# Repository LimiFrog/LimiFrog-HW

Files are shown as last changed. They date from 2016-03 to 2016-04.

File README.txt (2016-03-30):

LimiFrog-HW, ReadMe file
========================

This repository contains hardware information related to the LimiFrog harwdare: board, module assemble, casing...

******
NOTE: 
Datasheets of Integrated Circuits used on the board and other information of direct interest for programmers is stored in repository LimiFrog-SW, under directory "documentation"
*******

Contents of LimiFrog-HW repo :
-----------------------------

/3D-PRINTABLE_CASES :
Sources files (openscad) and STL files to 3D-print protective cases for LimiFrog.

/MODULE_HW :
Instructions to assemble and manipulate safely LimiFrog.

/BOARD :
Board design information

.
Example software for this board can be found in repo LimiFrog-SW. The /documentation directory present there also contains some hardware information that is of direct interest to programmers.

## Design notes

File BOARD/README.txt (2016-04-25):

Directory Contents :
-------------------

> LimiFrog_Board_Main_Parts_And_Interconnections.pdf
  --> Overview of the main parts present on the board and their interconnections

> LimiFrog_0.2a_SchematicDoc.pdf
  --> Full board schematic, provided under the Attribution-NonCommercial-ShareAlike 4.0 International license (CC BY-NC-SA). 
      See ../Licenses.txt .

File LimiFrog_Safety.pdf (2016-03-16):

### SAFETY RECOMMENDATIONS for LimiFrog users

V0.1 – March 2016

1) Never involve LimiFrog in any way in a medical or life-sustaining device.
2) LimiFrog is a prototyping platform and should not be used “as is” an an end-product.
3) LimiFrog includes a LiPo (lithium-polymer) battery.

A set of safety recommendations provided by the manufacturer of the battery is available in the product specification, which can be found on-line at this location : https://github.com/LimiFrog/LimiFrog-HW/blob/master/MODULE_HW/Battery_Specification.pdf

For convenience a copy of the safety paragraph is provided below :

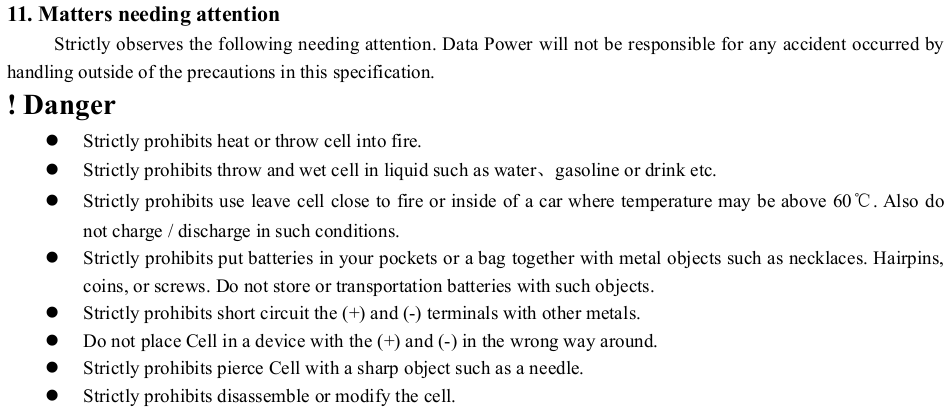
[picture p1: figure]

(continued on next page)

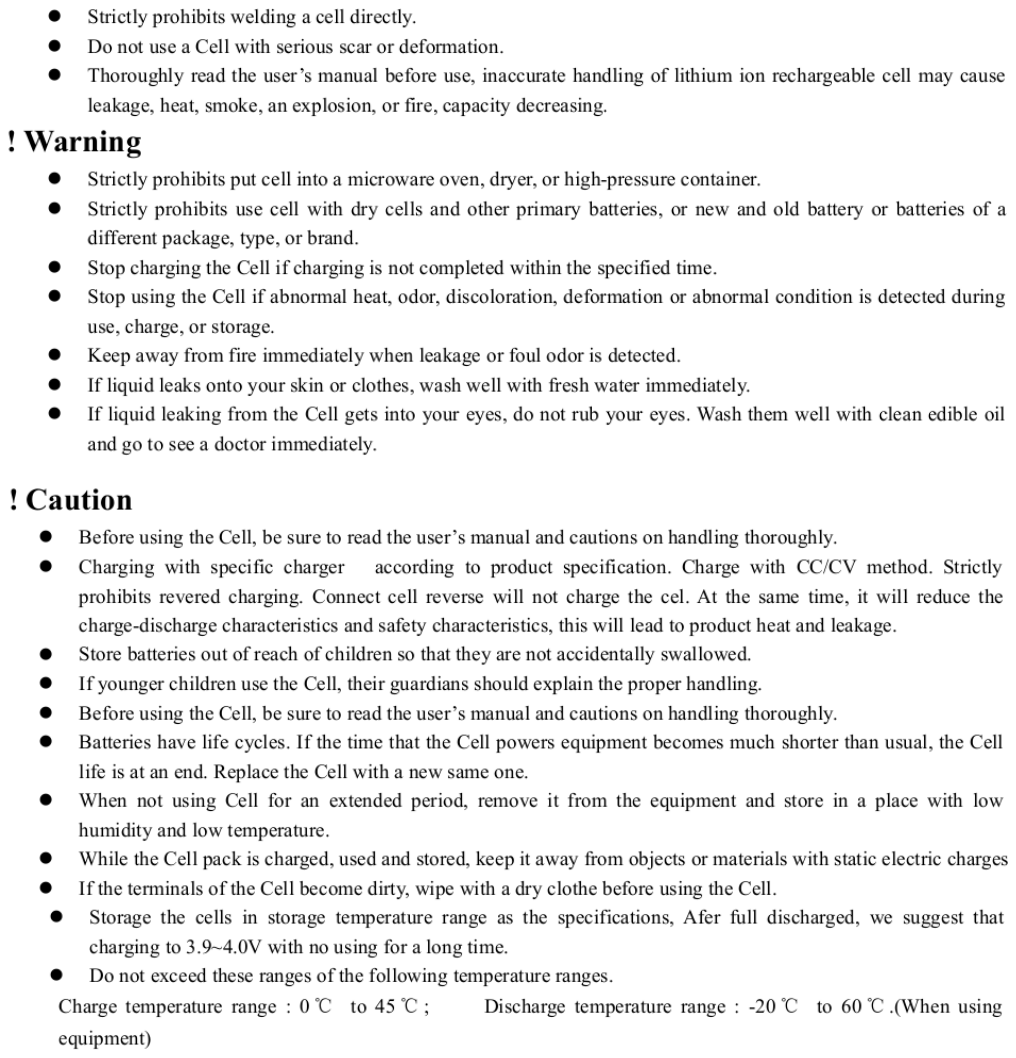
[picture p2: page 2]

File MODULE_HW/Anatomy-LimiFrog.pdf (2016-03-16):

OLED Display

# Anatomy of LimiFrog

Case opening for

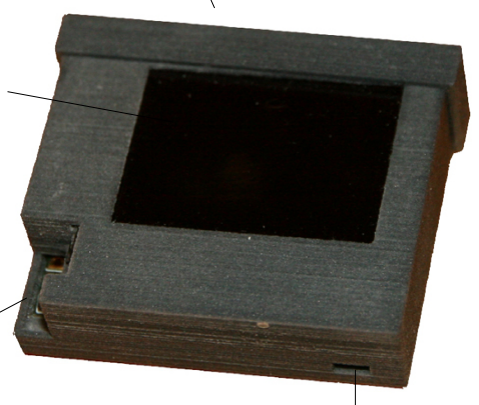
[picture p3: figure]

ambient light sensor /
proximity detector
Slot for sound to
microphone

Removable lid

BACK

STM32 Program /
Debug interface
(SWD)

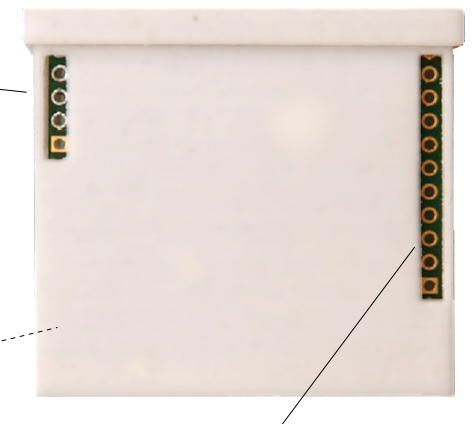
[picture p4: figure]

Extension port
(configurable digital/analog interfaces)

TOP (Lid Removed)

Micro-USB plug
(receptacle)

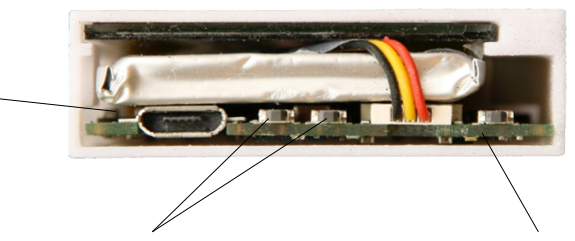
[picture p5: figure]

ON/OFF switch
(mini push-button)
+ See next page

LimiFrog-0.1 :
2 general-purpose switches (mini push-button)
LimiFrog-0.2:
1 general-purpose switch

(Not exposed here)
BlueTooth module
SWD interface
(optional use)

Operation of ON/OFF switch (mini push-button)

> From OFF state:
Press ON/OFF switch for about 0.5s to switch ON

> From ON state:

- ON/OFF signal routed to STM32 GPIO, behavior software-dependent. The provided software implements a “soft power off”:
Briefly pressing ON/OFF triggers an interrupt that switches off the full board after 3 brief LED flashes.
- Press ON/OFF switch for >5 s to cause a “hard power off” :
Board is switched off without CPU intervention.
(Useful in case STM32 code has hung and cannot execute the soft power off sequence)

External ON/OFF

> The ON/OFF signal driven by the push-button is also routed to the outermost position of the 5-pin connector that bears the STM32 SWD interface. This allows to control the ON/OFF signal from outside the board (e.g. by connecting to an external switch) rather than from the small push-button. The external switch must pull ON/OFF low to assert it and leave it open when not asserting it.

# LimiFrog-0.2 Board – Top and Bottom Views

## TOP VIEW

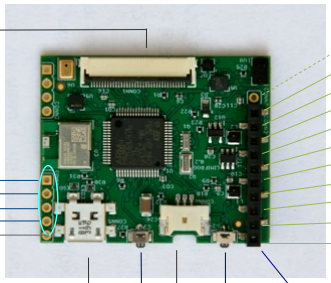
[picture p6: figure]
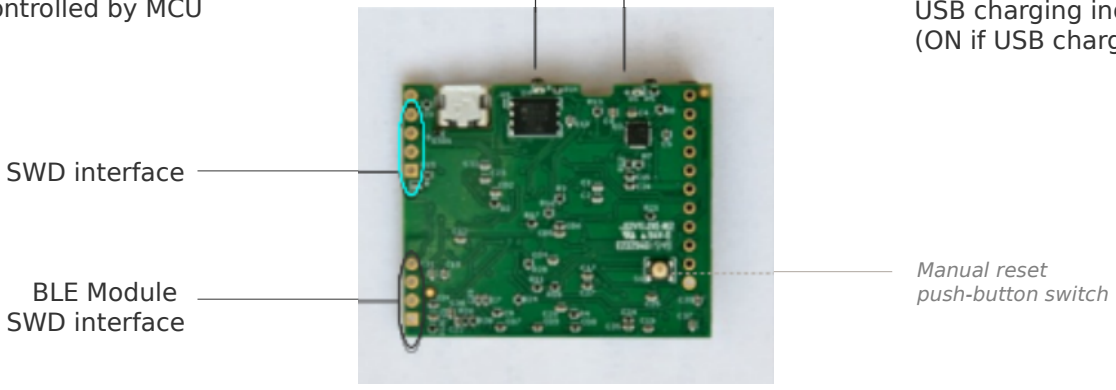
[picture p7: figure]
BLE Module; push-button switch; SWD interface

## BOTTOM VIEW

LED D4
RED
Controlled by MCU

LED D1
AMBER
USB charging indicator
(ON if USB charging)

STM32
SWD
interface

#1: VCC

#2: GND

#3: SWCK

#4: SWDIO

Extension Port
Position 1: Analog MIC output (also PB10) Position 2: digital GPIO (PA6)
Position 3: digital GPIO (PA4)
Position 4: digital GPIO (PA3)
Position 5: digital GPIO (PA2) Position 6: VCC_LDO (OFF or 3.3V) Position 7: digital GPIO (PA1) Position 8: digital GPIO (PA0) Position 9: GND
Position 10: digital GPIO (PB8) Position 11: digital GPIO (PB9) #5: external ON/OFF

STM32 SWD interface

ON/OFF

General Purpose
Push-Button Switch

Manual reset

Battery Connector

USB Connector

OLED Display
Connector

Female Socket Connector
on ext port positions 2 to 11 (dual top+bottom entry)

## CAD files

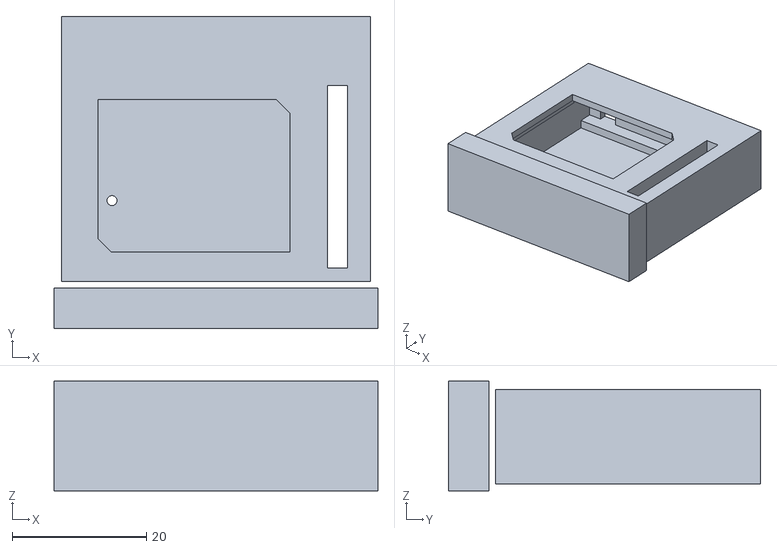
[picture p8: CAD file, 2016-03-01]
3D-PRINTABLE_CASES/Model_C-1.5.stl
48.2 x 46.5 x 16.4

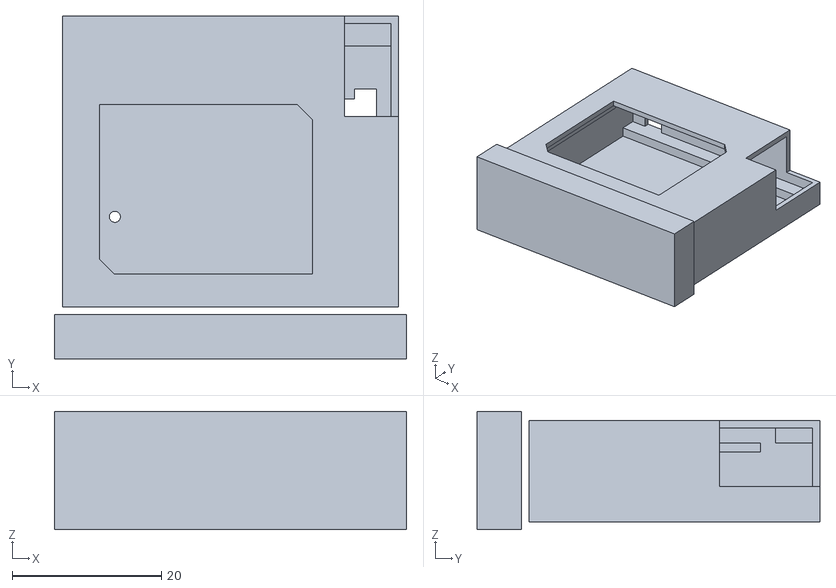
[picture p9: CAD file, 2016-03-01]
3D-PRINTABLE_CASES/Model_D-1.stl
47.2 x 46.0 x 15.8

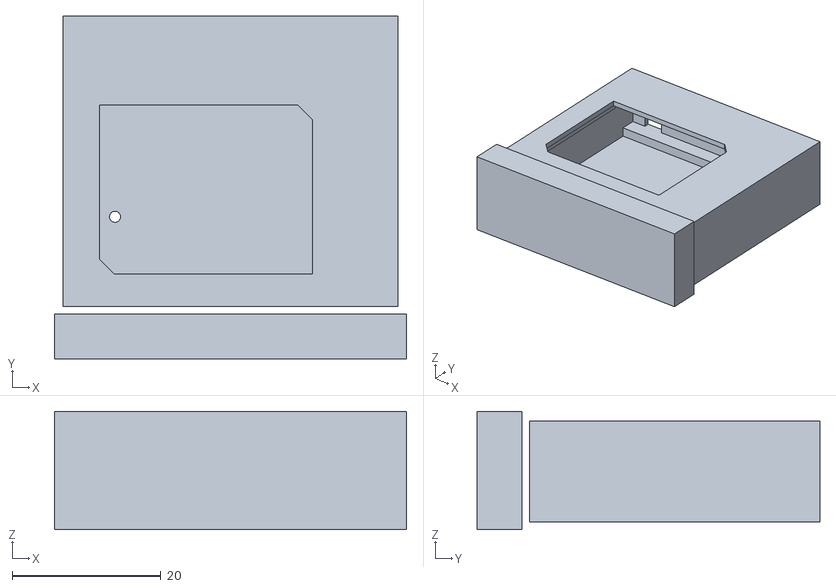
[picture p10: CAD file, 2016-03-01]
3D-PRINTABLE_CASES/Model_E-1.stl
47.2 x 46.0 x 15.8

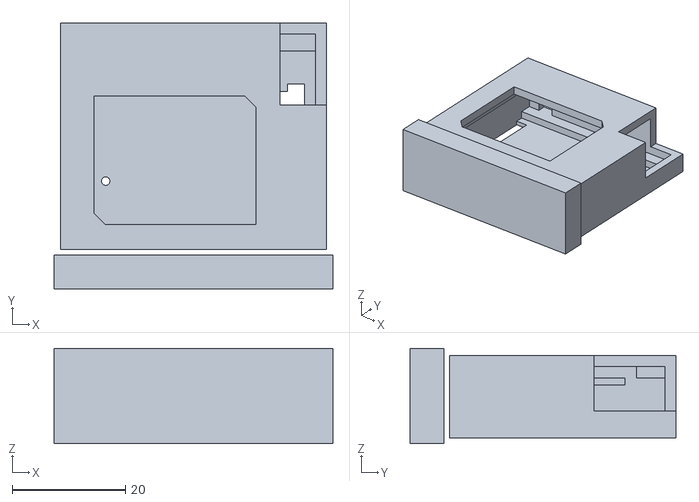
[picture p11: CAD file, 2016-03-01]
3D-PRINTABLE_CASES/Model_A-2.stl
49.2 x 47.0 x 16.9

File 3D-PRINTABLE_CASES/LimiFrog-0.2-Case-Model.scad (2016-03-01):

/**************************************************/
/*  This is a model of case for LimiFrog 0.2      */
/*  (the version shipped to Kickstarter backers)  */
/*                                                */
/* It is intended for a stacked configuration,    */
/* the battery lies between the board and the     */
/* display                                        */
/* The user may choose to enable/disable the      */
/* generation of some geometries (typically,      */
/* openings for connectors) by commenting out some*/
/* sections of this code.                         */
/* Wall thickness can also be configured.         */
/**************************************************/

/**************************************************/
/* The XY plane is parallel to the display,       */
/* Z axis is normal to the display.               */
/*                                                */
/* Code does the following:                       */
/* - describe 7 stacked "slices" along XY plane   */
/*   Each slice is described in 2D then extruded  */
/*    along Z axis                                */
/* - then add openings for the VL6180X sensor,    */
/*   for the microphone, for the extension port,  */
/*   for the program & debug connectros etc.      */
/* - finally lid is described                     */
/**************************************************/


/* == Construction Parameters  ===================*/ 

// You may want to change the following
Twall = 1;      // Wall thickness
Twall_lid = 1;  // Lid wall thickness 


// Better not change this unless you know what 
// you're doing

epsilon = 0.5;

Xboard=42.4; // real size 42.4 , will add some margin when computing Xin
Yboard=35;   // real size 34.6 + some margin

Yflex = 3;   // to accomodate curve of flexible connector from board to display

// Internal dimensions of the case :
Xin = Xboard + 0.6;  
Yin = Yboard + Yflex;

// Screen (i.e. display) dimensions + slight margin
// (real dimensions @ no margin = 35.8x30.8)
Xscreen = 36; 
Yscreen=31; 

// (X-)Margin that allows display to slide within the guide
ScreenMargin = 0.8;

// Distance between holes for extension port
// and holes for STM32/BME SWD ports
LR_Connectors_Dist = 15*2.54;


// Slice 1 parameters
h1 = 1; // = thickness of box bottom

// Slice 2 parameters
h2 = 1+0.8; // = thickness of PCB + bottom-side components

// Slice 3 parameters
h3 = 2; // = max thickness of top components

// Slice 4 parameters
h4 = 4.6; // = max battery thickness
// Side battery blockers suppressed

// Slice 5 parameters
h5 = 1.2; // = thickness of OLED supports (rails) - also allows to squeeze battery wires

// Dimesion of the rails over which the OLED display
// is expected to slide
X_OledSupport = 1.3;
Y_OledSupport_left = Yscreen;
Y_OledSupport_right = Yscreen*0.7;

// Slice 6 parameters
h6 = 1.7+0.3; // = thickness of OLED + slight margin
Ybutee = 5; Xbutee = 1; //dimensions of stop part that prevents OLED to slide too far inside the case
 
// Slice 7 parameters
h7 = Twall; // = thickness of box top
// dimensions of active region of the display:
Xdisplay_active = 28.6; 
Ydisplay_active = 22.7; 
// Translation factors to get the case opening to match the position of the display's active region
Display_LeftMargin = 3.9; 
Display_TopMargin = 5.9; 

// Parameters for openings for VL6180X and mic
Y_VL6180X_CornerOpen= 9.5+Yflex; 
Mic_opening_Xleft = 2.9;
Mic_opening_Xright =6.9;
Mic_opening_Z = 2;



/* == Now actually describe the case =============*/ 

// Generic module re-used multiple times below
module shell_TopView()
{
    difference()
    {
        translate([-Twall,0,0])
        square([Xin+2*Twall, Yin+Twall]);
        
        square([Xin, Yin]);
    }
}


// ----------------------------------------------
// Slice 1 (bottom of box)
module slice1_TopView()
{
        translate([-Twall,0,0])
        square([Xin+2*Twall, Yin+Twall]);
}
    
module slice1()
{
    linear_extrude(height=h1)slice1_TopView();
}
    

// ----------------------------------------------
// Slice 2 -- PCB + bottom components padding
module slice2_TopView()
{
    difference()
    {
        translate([-Twall,0,0])
        square([Xin+2*Twall, Yin+Twall]);
        
        square([Xin, Yboard]);
    }
}
module slice2()
{
    linear_extrude(height=h2)
        slice2_TopView();
}
    

// ----------------------------------------------
// Slice 3 -- Top components + some margin
module slice3_TopView()
{
    shell_TopView();
}
module slice3()
{
    linear_extrude(height=h3)
        slice3_TopView();
}
    

// ----------------------------------------------
// Slice 4 -- Battery side 
module slice4_TopView()
{
    shell_TopView();
 // no side blockers anymore
}
module slice4()
{
    linear_extrude(height=h4)
        slice4_TopView();
}
    

// ----------------------------------------------
// Slice 5 -- OLED support (rails)
module slice5_TopView()
{
    shell_TopView();
    square([X_OledSupport, Y_OledSupport_left]); 
    translate([Xscreen-X_OledSupport,0,0])
      square([Xin-Xscreen+X_OledSupport, Y_OledSupport_right]);
}
module slice5()
{
    linear_extrude(height=h5)
        slice5_TopView();
}
    
// ----------------------------------------------
// Slice 6 -- OLED guide (rails)
module slice6_TopView()
{
    difference()
    {
        translate([-Twall,0,0])
        square([Xin+2*Twall, Yin+Twall]);
        
        square([Xscreen+ScreenMargin, Yin]);
     /* ONLY IF NO TOP OPENING ON EXT PORT :   
        //Also,  remove material for cost optimisation :
        translate([Xscreen+ScreenMargin, 3, 0])
            square([Xin-(Xscreen+ScreenMargin),3]);
        translate([Xscreen+ScreenMargin, 9, 0])
            square([Xin-(Xscreen+ScreenMargin),3]);
        translate([Xscreen+ScreenMargin, 15, 0])
            square([Xin-(Xscreen+ScreenMargin),3]);
     */
    }
    
  translate([0, Yin-Ybutee, 0])
    square([Xbutee, Ybutee]);
    
}
module slice6()
{
    linear_extrude(height=h6)
        slice6_TopView();
}
    

// ----------------------------------------------
// Slice 7 -- box top with opening
module slice7_TopView()
{
    difference()
    {
        translate([-Twall,0,0])
        square([Xin+2*Twall, Yin+Twall]);
        
        translate([Display_LeftMargin, 
        Yin-(Ybutee+Display_TopMargin+Ydisplay_active),0])
        square([Xdisplay_active, Ydisplay_active]);
    }
    
    // "Fill" 2 opposite corners for aesthetic & robustness
    Screen_TopRightX = Display_LeftMargin+Xdisplay_active;
    Screen_TopRightY = Yin-(Ybutee+Display_TopMargin);
    Screen_BotLeftX = Display_LeftMargin;
    Screen_BotLeftY = Yin-(Ybutee+Display_TopMargin+Ydisplay_active);

    polygon(points=[ [Screen_TopRightX,Screen_TopRightY],
                     [Screen_TopRightX-2,Screen_TopRightY],
                     [Screen_TopRightX,Screen_TopRightY-2] 
                    ]);
    polygon(points=[ [Screen_BotLeftX,Screen_BotLeftY],
                     [Screen_BotLeftX+2,Screen_BotLeftY],
                     [Screen_BotLeftX,Screen_BotLeftY+2] 
                    ]);

}
module slice7()
{
    linear_extrude(height=h7)
        slice7_TopView();
}
    

// ----------------------------------------------
// Assemble the above slices into complete case :

module box_tmp()
{
  union()
  {
    slice1();
    
    translate([0, 0, h1])
    slice2();

    translate([0, 0, h1+h2])
    slice3();
    
    translate([0, 0, h1+h2+h3])
    slice4();

    translate([0, 0, h1+h2+h3+h4])
    slice5();

    translate([0, 0, h1+h2+h3+h4+h5])
    slice6();

    translate([0, 0, h1+h2+h3+h4+h5+h6])
    slice7();
  }
}



/* == Add various openings to the case   ==========*/ 


module VL6180X_CornerCut()
{
    translate([Xscreen+ScreenMargin-0.01, Yin-Y_VL6180X_CornerOpen, h1+h2+h3]) 
      cube([Xin+Twall-(Xscreen+ScreenMargin)+epsilon, Y_VL6180X_CornerOpen+Twall+epsilon, h7+h6+h5+h4]);
}



module Mic_Opening()
{
  translate([Mic_opening_Xleft, Yin-epsilon, h1+h2])
     cube([Mic_opening_Xright-Mic_opening_Xleft, Twall+2*epsilon , Mic_opening_Z]);
}


module stm32SWD_Opening() //but posn5 (Boot0) not accessible
{
   X_hole = 3;
   Y_hole = 5*2.54 + 2.54/4;  // header pitch=2.54 mm
   translate([0,0,-2])
      cube([X_hole,Y_hole,5]);
    
   // Mark position 1
   translate([6, Y_hole-2.54/2, -2]) 
     linear_extrude(height=5)
      circle(d=1.5, $fn=16);
      
}

module bleSWD_Opening()
{
   X_hole = 3;
   Y_hole = 4*2.54+2.54/4;  // header pitch=2.54 mm
   translate([0,2+8*2.54,-2])
      cube([X_hole,Y_hole,5]);
}

module ExtensionPins_Opening() 
{
   X_hole = 3;
   Y_hole = 10*2.54 + 2.54 + 2.54/2;  // header pitch=2.54 mm
   translate([LR_Connectors_Dist, 0, -2]) 
     cube([X_hole,Y_hole,5]);
}

module ResetButton_Opening() 
{
   X_RstBut = 5;
   Y_RstBut = 5;  
   translate([LR_Connectors_Dist-X_RstBut, 9*2.54, -2])
     cube([X_RstBut,Y_RstBut,5]);
}
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

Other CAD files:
3D-PRINTABLE_CASES/Model_E-1.5.stl
3D-PRINTABLE_CASES/Model_D-1.5.stl
3D-PRINTABLE_CASES/Model_A-1.5.stl
3D-PRINTABLE_CASES/Model_F-1.5.stl
3D-PRINTABLE_CASES/Model_A-1.stl
3D-PRINTABLE_CASES/Model_B-1.stl
3D-PRINTABLE_CASES/Model_F-1.stl
3D-PRINTABLE_CASES/Model_A-3.stl
3D-PRINTABLE_CASES/Model_B-1.5.stl

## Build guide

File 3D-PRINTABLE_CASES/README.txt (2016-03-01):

This directory contains 3D-printable models of protective cases for LimiFrog.

The models were built using the Openscad modelling software (can be freely downloaded on the web).
File LimiFrog-0.2-Case-Model.scad is the OpenScad source file.

Files Model_xxx.stl are all derived from this master source file, using different settings for wall thickness and presence/absence of some features.
File Case_Models.pdf lists the available variants.

You may also create your own variants by tinkering with the Openscad source file.

The STL format is suitable for usage with any 3D-printer or to send to an on-line 3D printing service.
There are free STL viewers available on-line if you want to view the proposed cases.

The choice of wall thickness depends on the capabilities of the target 3D printer and on the required robustness and rigidity of the printed case.

It is possible to use a wall thickness of 1mm to print this case using e.g. Sculpteo's online 3D-printing services, in basic white plastic (it's nylon, actually). The result is slightly flexible and reasonably robust (but not fit to sustain severe stress).
I have also used 1mm to print in ABS on a professional machine from a local 3D-printing specialist.
For DIY 3D-printers, 1.5 or 2mm thickness may be more appropriate.

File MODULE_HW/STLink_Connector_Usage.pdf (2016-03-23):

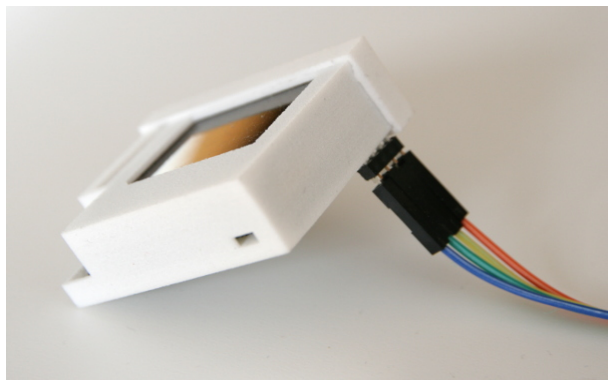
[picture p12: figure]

# Connecting your ST-Link device to LimiFrog

V0.2 – March 2016

## Reminder: Principle

ST-Link / V2
device

SWD interface (4 lines) :

- swclk (clock)
- swdio (data)
- vcc (positive supply)
- gnd (ground)

4

> An ST-Link/V2 device acts as a 'bridge' between a host PC and LimiFrog.
It enables downloading (and debuggging) code from the host PC into LimiFrog.

> It connects to the host PC via USB and
to LimiFrog via a specialized 'SWD' interface (4 wires).

> The SWD port provides access to the STM32 micro-controller.

ARM core
(STM32)

LimiFrog

Host PC

USB

## SWD port location on board

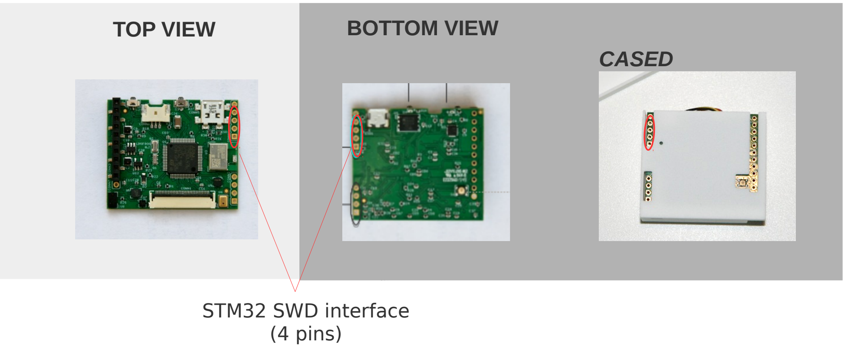
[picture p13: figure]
BOTTOM VIEW; STM32 SWD interface (4 pins); TOP VIEW; CASED

## Header and wires for connecting to LimiFrog's SWD port

> LimiFrog comes with a removable 4-pin male header that can be plugged into the SWD port of LimiFrog.

> One end of this 4-pin header is slightly 'swollen' : this end goes into the holes of the SWD port. The swelling facilitates mechanical contact, hence good electrical connection.
The other end plugs into the wires of e.g. four “Dupont Line” wires (provided).
“Dupont Line” type wires | 4-pin male header

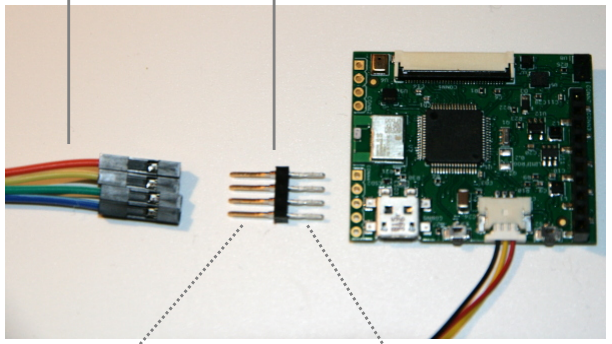
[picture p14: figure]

regular end | 'swollen' end

## Connecting to LimiFrog

Pin 4 = SWDIO (data)
Pin 3 = SWCLK (clock)
Pin 2 = GND | (ground reference)
Pin 1 = VCC | (positive supply, typ. 3V)

( Pin 5, not part of SDW interface )

Pin 1 indicator on plastic package

#4

#3

#2

#1

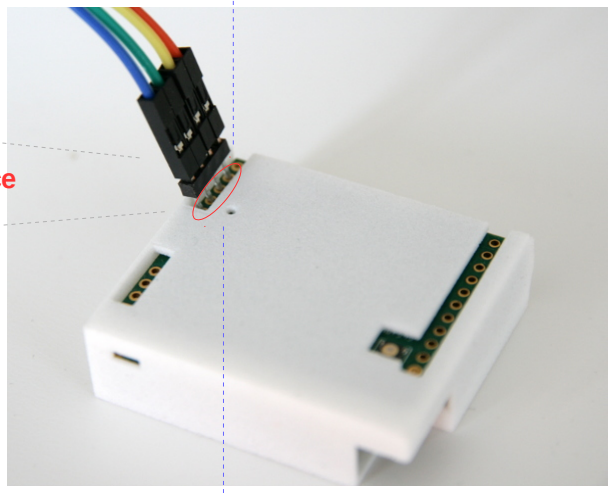
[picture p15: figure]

SWD interface

- Recommended installation when programming the board :
- The module weights on the 4-pin header

so electrical contact is facilitated.
- If proper contact is not established, press slightly downwards.

(#5)

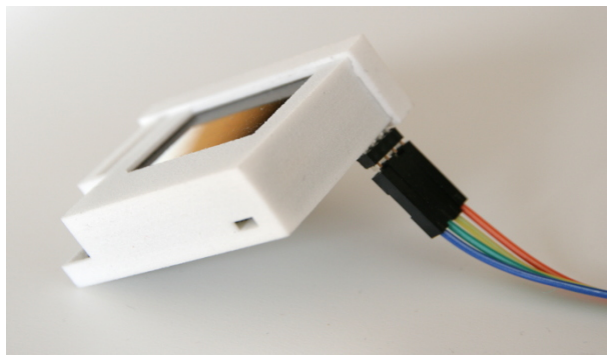
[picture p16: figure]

## Other side of the wires: ST-Link/V2 device (examples)

> Identify the following signals on your ST-Link/V2 device :
SWIDIO, SWCLK, GND, VCC/VDD
> Connect them to the relevant wires
> Next are a few examples : | Low-cost ST-Link/V2 compatible dongle
Nucleo Board used as ST-Link/V2 device (refer to STM32 Nucleo User Manual) | SWDIO

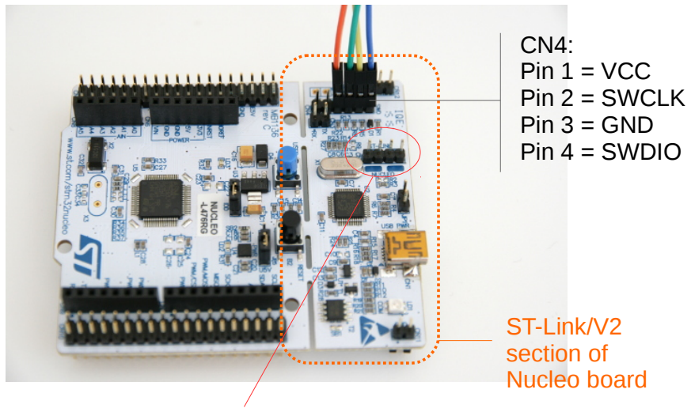
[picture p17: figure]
ST-Link/V2 section of Nucleo board; CN4: Pin 1 = VCC Pin 2 = SWCLK Pin 3 = GND Pin 4 = SWDIO
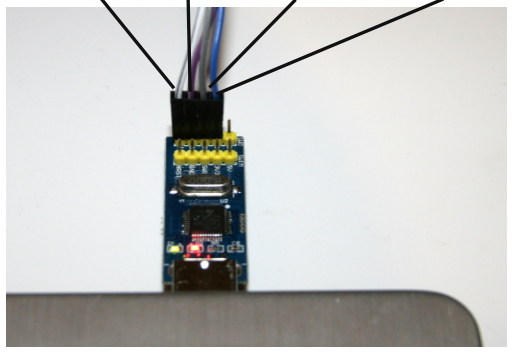
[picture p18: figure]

- Connector CONN2 must be removed to use Nucleo as stand-alone ST-Link/V2
- LimiFrog must be ON to provide 3V on Nucleo ST-Link/V2 VCC pin
SWCLK | GND | VCC

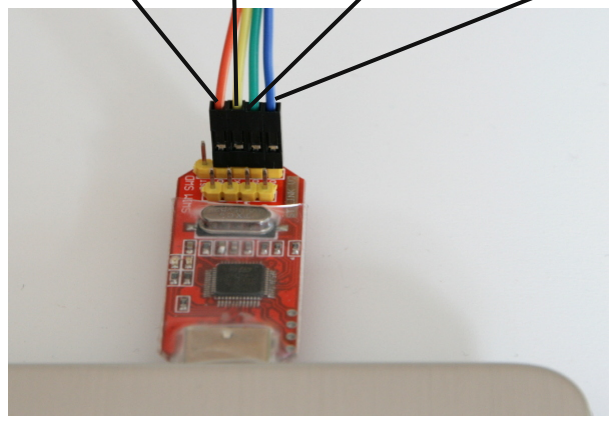
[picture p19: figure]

SWDIO | GND | SWCLK | VCC

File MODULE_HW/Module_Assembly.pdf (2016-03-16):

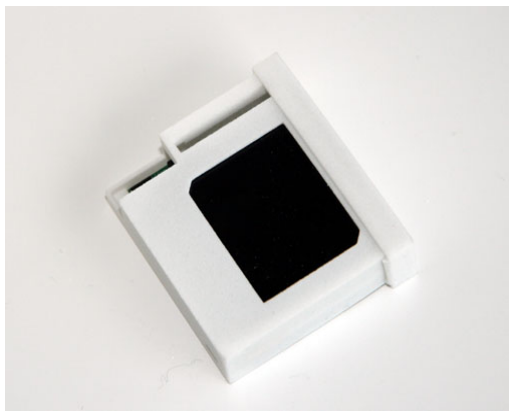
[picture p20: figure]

# Assembling your LimiFrog module

If your version of LimiFrog features no display and perhaps no case, just ignore the steps that pertain to these features.

V0.1 – March 2016

## Step 1: Beware of static electricity

First make sure you are not electrically charged.
To that aim, you could for example touch a metal part that is grounded to earth.

This is because, although reasonably well protected by specialized internal structures, integrated circuits can be damaged by electrostatic discharges (ESD)

## Step 2: Connect the LiPo battery

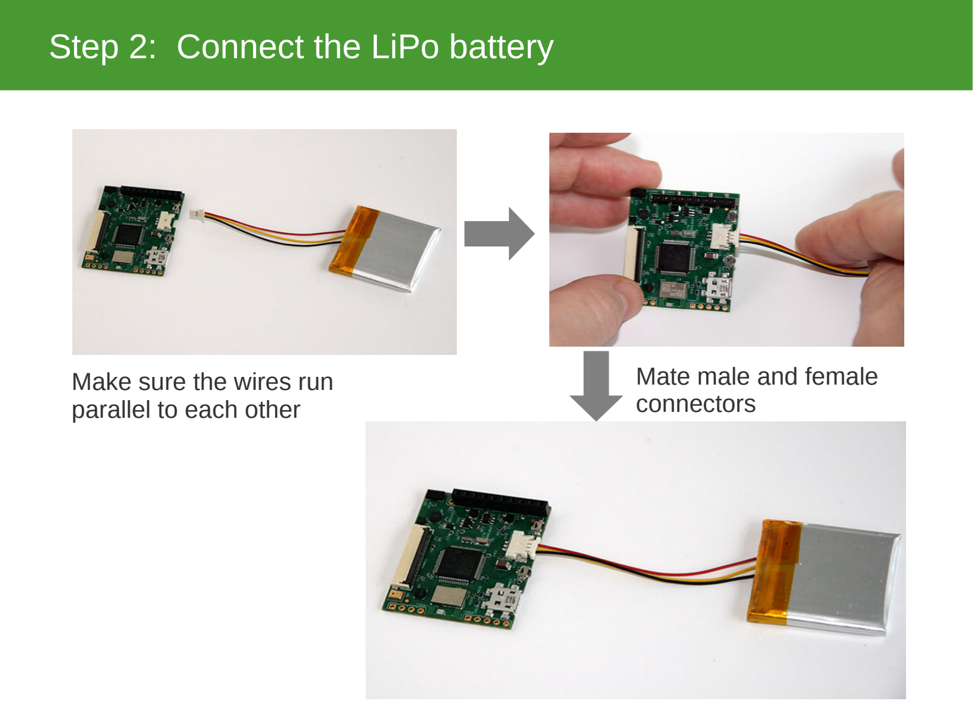
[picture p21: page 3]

Make sure the wires run
parallel to each other

Mate male and female
connectors

## Step 3: Connect the OLED display

a) Make sure the rotary backlock connector is open (pull up the black lever)
b) Fully insert the flexible OLED connector (a.k.a FPC) into the slot
of the backlock connector
*** Pay attention to OLED orientation (face down as on photo)

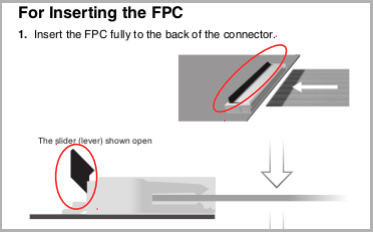
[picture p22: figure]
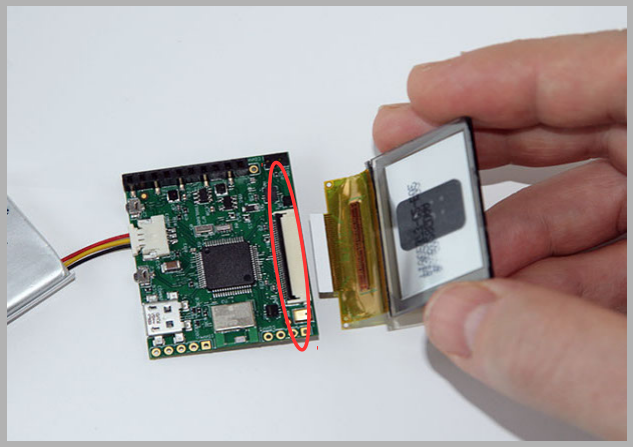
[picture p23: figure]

Manufacturer's recommendations for operating backlock connector copied at the end of this document and available in full on LimiFrog's GitHub, documentation, section: https://github.com/LimiFrog/LimiFrog-HW/Module_HW

=

## Step 3: Connect the OLED display (continued)

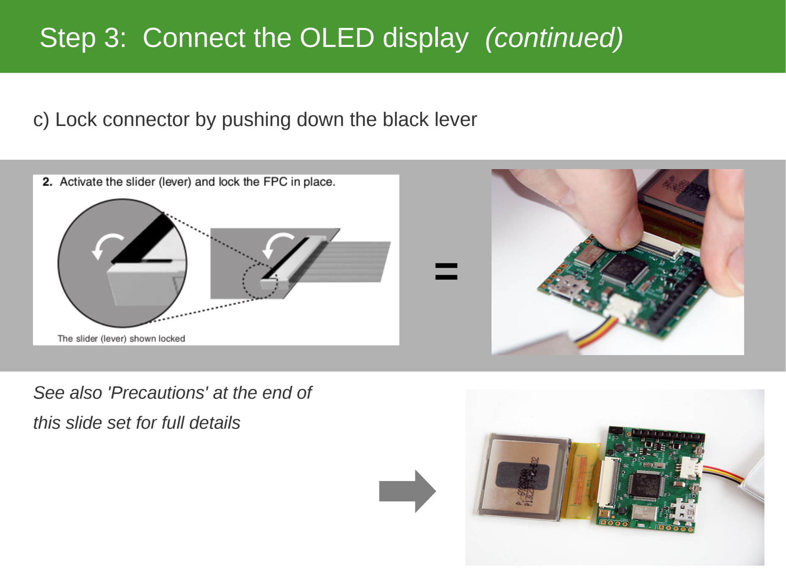
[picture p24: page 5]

c) Lock connector by pushing down the black lever

=

See also 'Precautions' at the end of this slide set for full details

## Step 4 : Stack the battery

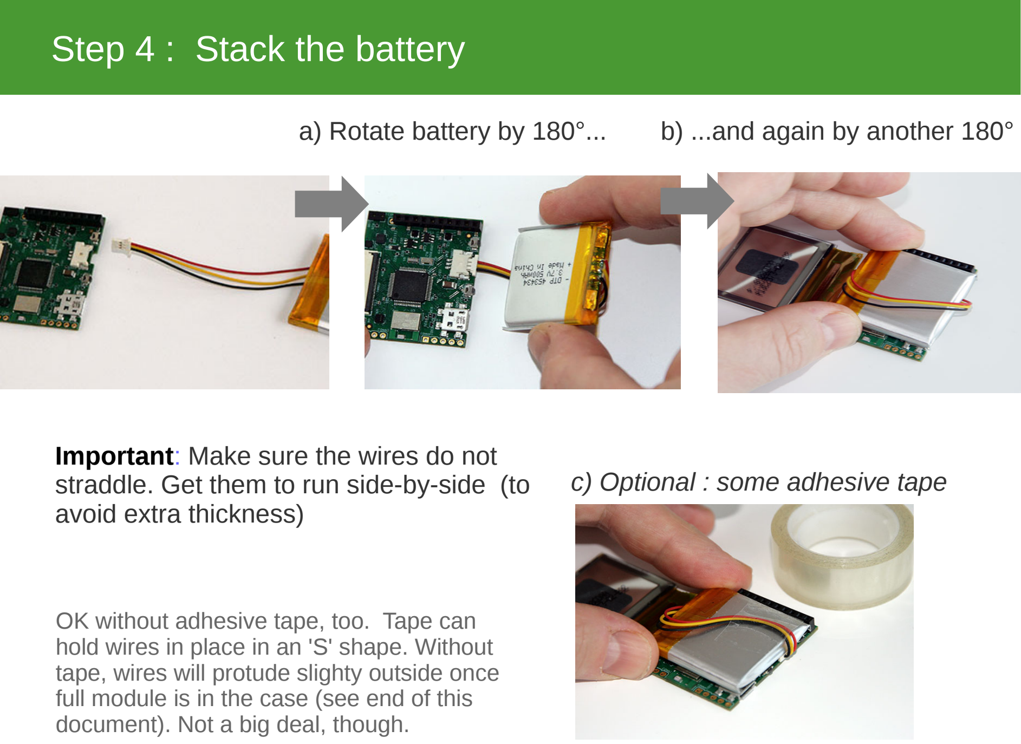
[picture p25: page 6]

a) Rotate battery by 180°... b) ...and again by another 180°
c) Optional : some adhesive tape

Important: Make sure the wires do not straddle. Get them to run side-by-side (to avoid extra thickness)

OK without adhesive tape, too. Tape can hold wires in place in an 'S' shape. Without tape, wires will protude slighty outside once full module is in the case (see end of this document). Not a big deal, though.

## Step 5 : Stack the OLED and insert module

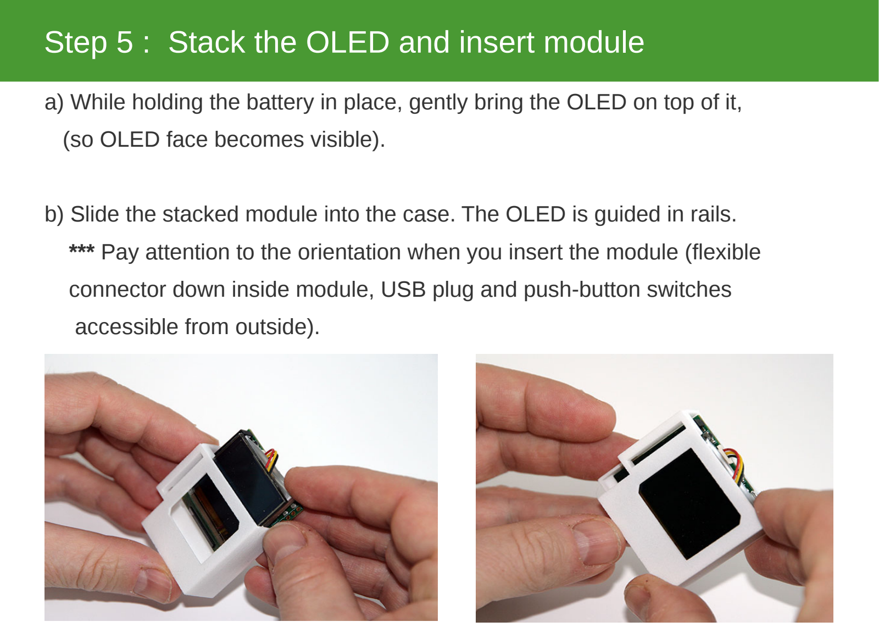
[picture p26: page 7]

a) While holding the battery in place, gently bring the OLED on top of it, (so OLED face becomes visible).
b) Slide the stacked module into the case. The OLED is guided in rails. *** Pay attention to the orientation when you insert the module (flexible connector down inside module, USB plug and push-button switches accessible from outside).

## Your LimiFrog module is ready for use !

Here battery wires were not maintained by
adhesive tape. They tend to protude a little outside the case (acceptable)

Here adhesive tape was used to hold the wires in a 'S' shape on top of battery and to prevent them from protuding a little.

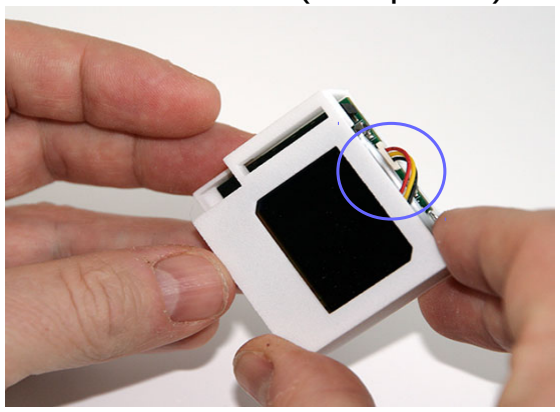
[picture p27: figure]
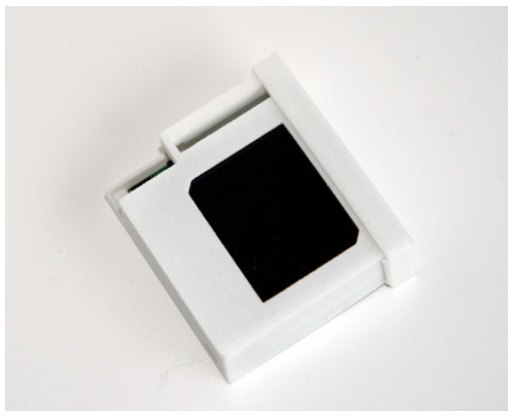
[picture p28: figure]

With the lid...

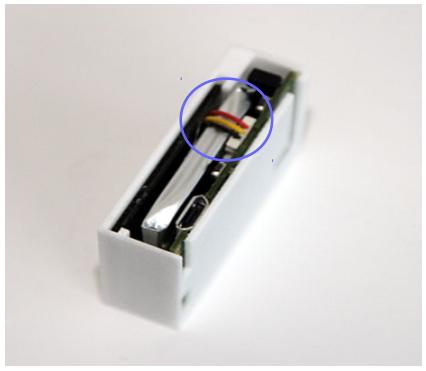
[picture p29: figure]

## APPENDIX (1) - In case you need to disconnect the display

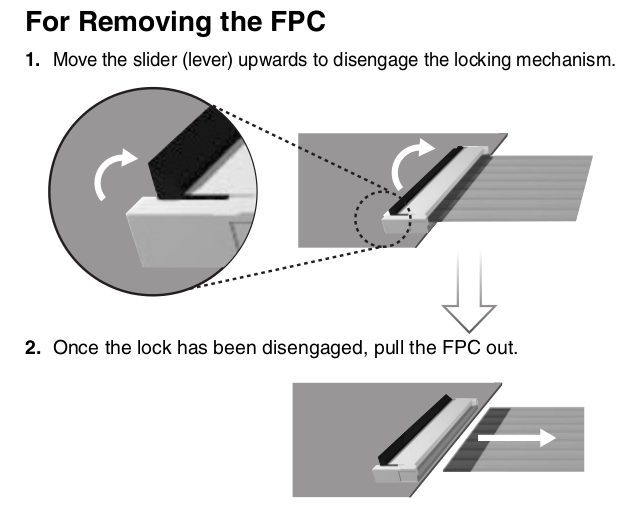
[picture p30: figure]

## Other precautions for FPC

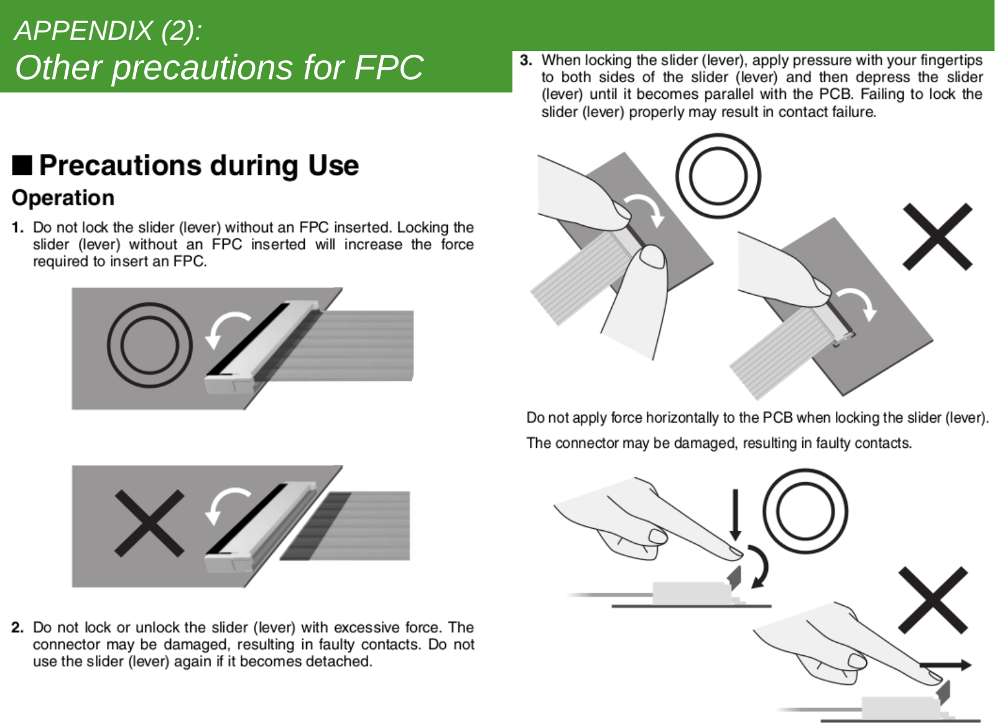
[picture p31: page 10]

APPENDIX (2):

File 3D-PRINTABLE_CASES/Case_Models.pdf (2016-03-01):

Sheet1

Page 1

Model Name | A-1 | B-1 | C-1 | D-1 | E-1 | F-1 | A-1.5 | B-1.5 | C-1.5 | D-1.5 | E-1.5 | F-1.5 | A-2
1mm | 1mm | 1mm | 1mm | 1mm | 1mm | 1.5mm 1.5mm 1.5mm | 1.5mm | 1.5mm | 1.5mm | 2mm
| Y | Y | Y | Y | Y | N | Y | Y | Y | Y | Y | N | Y
Hw reset button access | Y | Y | Y | Y | Y | N | Y | Y | Y | Y | Y | N | Y
| Y | Y | Y | N | N | N | Y | Y | Y | N | N | N | Y
| Y | Y | N | Y | N | N | Y | Y | N | Y | N | N | Y
| Y | N | N | N | N | N | Y | N | N | N | N | N | Y

Wall thickness

Bottom opening
For access to extension port

Top opening
For access to extension port

Opening for VL6180X
proximity sensor visibility

Opening for access to BLE
SWD interface

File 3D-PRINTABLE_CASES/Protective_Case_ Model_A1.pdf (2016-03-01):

- 1mm wall thickness, White plastic (nylon)
- Maximum access to connectors and ports :

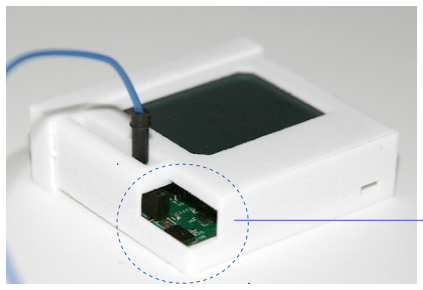
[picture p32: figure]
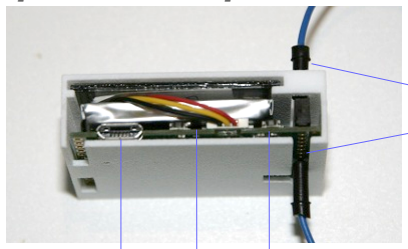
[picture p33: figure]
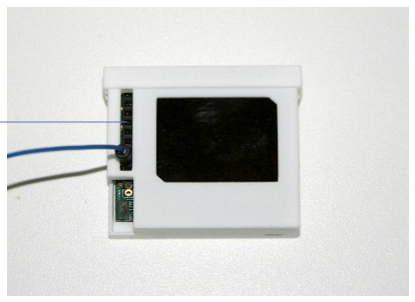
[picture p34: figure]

Top-side access to extension port positions 2 to 10

Case opening
for VL6180X optical detector visibility

Top (partial) and bottom (full) access to extension port (dual-entry female socket, 2.54m pitch)

USB connector

On/off mini-switch
General-purpose mini-switch

[with lid removed]

# 3D-printed case Model “A-1”

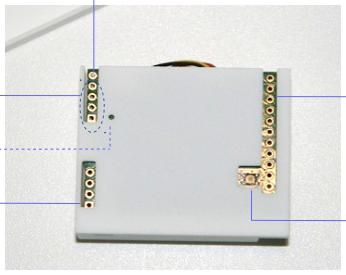
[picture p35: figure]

Bottom-side access
to extension port,
all positons (1 to 11)

Hardware reset
micro- push-button

Pins 1-4:
Access to STM32
SWD interface

Access to BLE module
SWD interface

STM32 SWD pin1 indicator

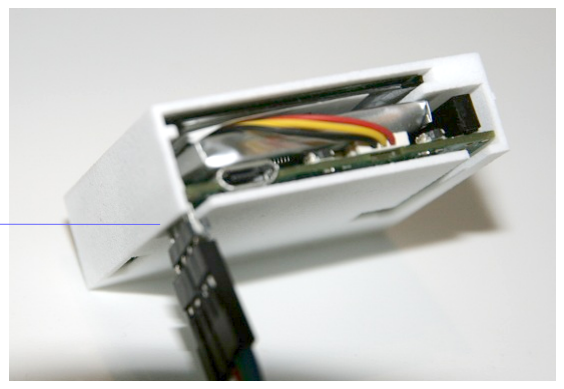
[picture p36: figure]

Pin5: ON/OFF access
(for optional external switch)

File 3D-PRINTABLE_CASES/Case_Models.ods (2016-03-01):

Model Name | A-1 | B-1 | C-1 | D-1 | E-1 | F-1 | A-1.5 | B-1.5 | C-1.5 | D-1.5 | E-1.5 | F-1.5 | A-2
Wall thickness | 1mm | 1mm | 1mm | 1mm | 1mm | 1mm | 1.5mm | 1.5mm | 1.5mm | 1.5mm | 1.5mm | 1.5mm | 2mm
Bottom opening For access to extension port | Y | Y | Y | Y | Y | N | Y | Y | Y | Y | Y | N | Y
Hw reset button access | Y | Y | Y | Y | Y | N | Y | Y | Y | Y | Y | N | Y
Top opening For access to extension port | Y | Y | Y | N | N | N | Y | Y | Y | N | N | N | Y
Opening for VL6180X proximity sensor visibility | Y | Y | N | Y | N | N | Y | Y | N | Y | N | N | Y
Opening for access to BLE SWD interface | Y | N | N | N | N | N | Y | N | N | N | N | N | Y

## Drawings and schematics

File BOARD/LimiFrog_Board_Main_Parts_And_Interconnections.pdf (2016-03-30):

# Hardware

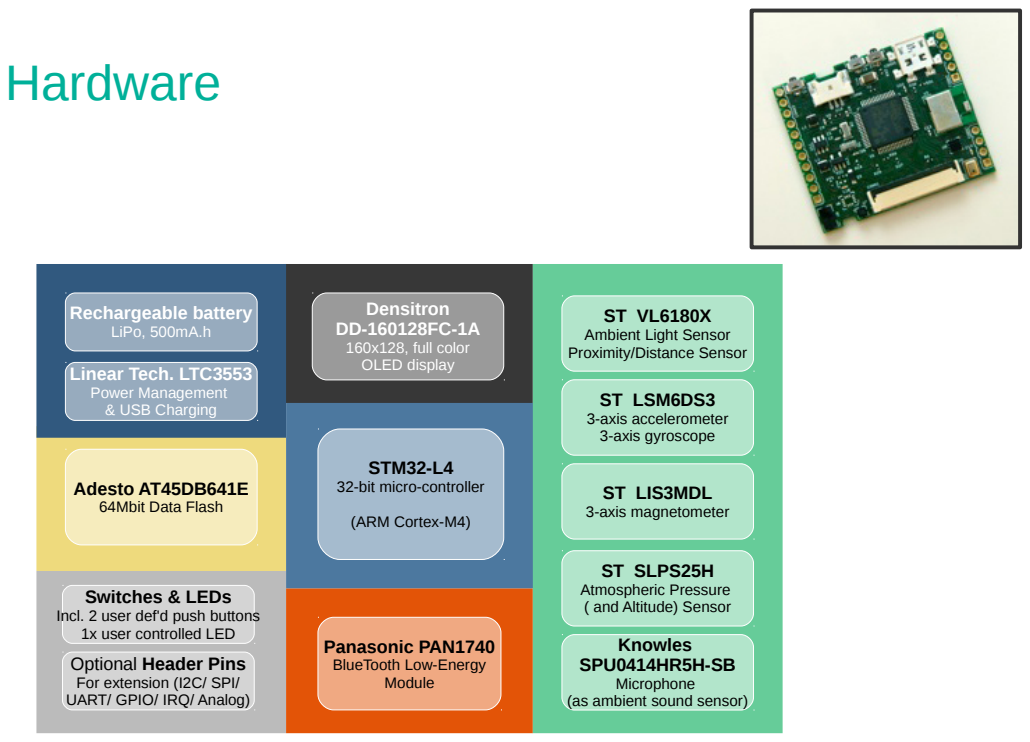
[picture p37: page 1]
(ARM Cortex-M4); Densitron DD-160128FC-1A 160x128, full color OLED display; Rechargeable battery LiPo, 500mA.h; Linear Tech. LTC3553 Power Management & USB Charging; Adesto AT45DB641E 64Mbit Data Flash; ST LSM6DS3 3-axis accelerometer 3-axis gyroscope; ST LIS3MDL 3-axis magnetometer

Ambient Light Sensor
Proximity/Distance Sensor

STM32-L4
32-bit micro-controller

ST SLPS25H
Atmospheric Pressure
( and Altitude) Sensor
Knowles
SPU0414HR5H-SB
Microphone
(as ambient sound sensor)

Switches & LEDs
Incl. 2 user def'd push buttons
1x user controlled LED
Optional Header Pins
For extension (I2C/ SPI/
UART/ GPIO/ IRQ/ Analog)

Panasonic PAN1740
BlueTooth Low-Energy
Module

# Major Connections

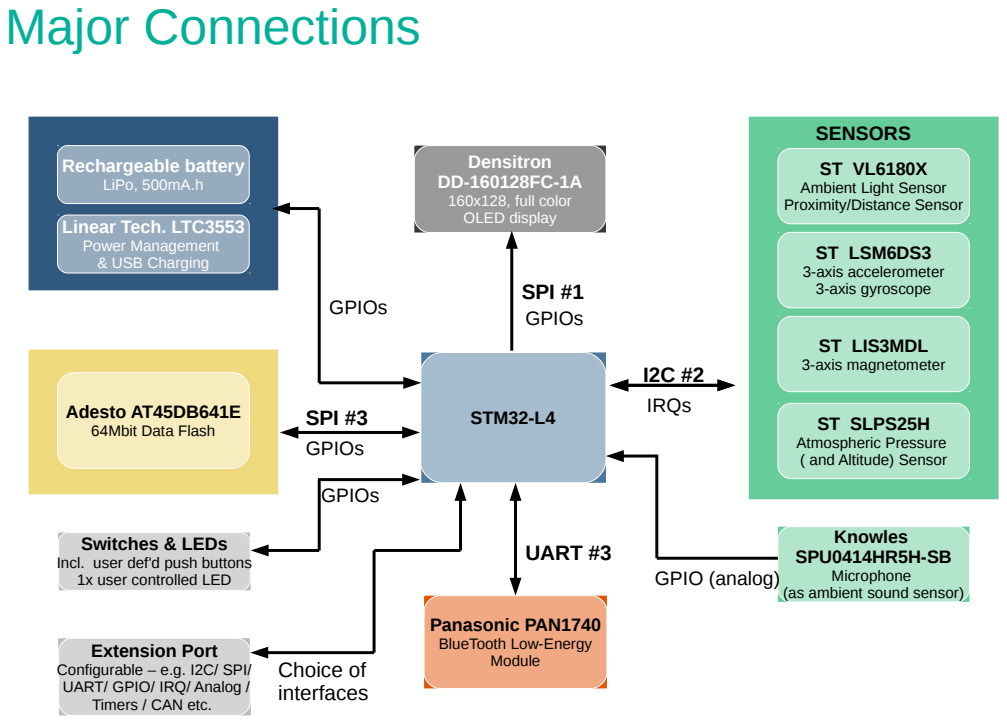
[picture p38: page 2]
STM32-L4; Densitron DD-160128FC-1A 160x128, full color OLED display; Rechargeable battery LiPo, 500mA.h; Linear Tech. LTC3553 Power Management & USB Charging; Adesto AT45DB641E 64Mbit Data Flash; ST LSM6DS3 3-axis accelerometer 3-axis gyroscope; ST LIS3MDL 3-axis magnetometer; SPI #1 GPIOs; I2C #2 IRQs; UART #3; GPIOs; SPI #3 GPIOs; GPIO (analog); Choice of interfaces

SENSORS
Ambient Light Sensor
Proximity/Distance Sensor

ST SLPS25H
Atmospheric Pressure
( and Altitude) Sensor

Switches & LEDs
Incl. user def'd push buttons
1x user controlled LED

Knowles
SPU0414HR5H-SB
Microphone
(as ambient sound sensor)

Panasonic PAN1740
BlueTooth Low-Energy
Module

Extension Port
Configurable – e.g. I2C/ SPI/
UART/ GPIO/ IRQ/ Analog /
Timers / CAN etc.

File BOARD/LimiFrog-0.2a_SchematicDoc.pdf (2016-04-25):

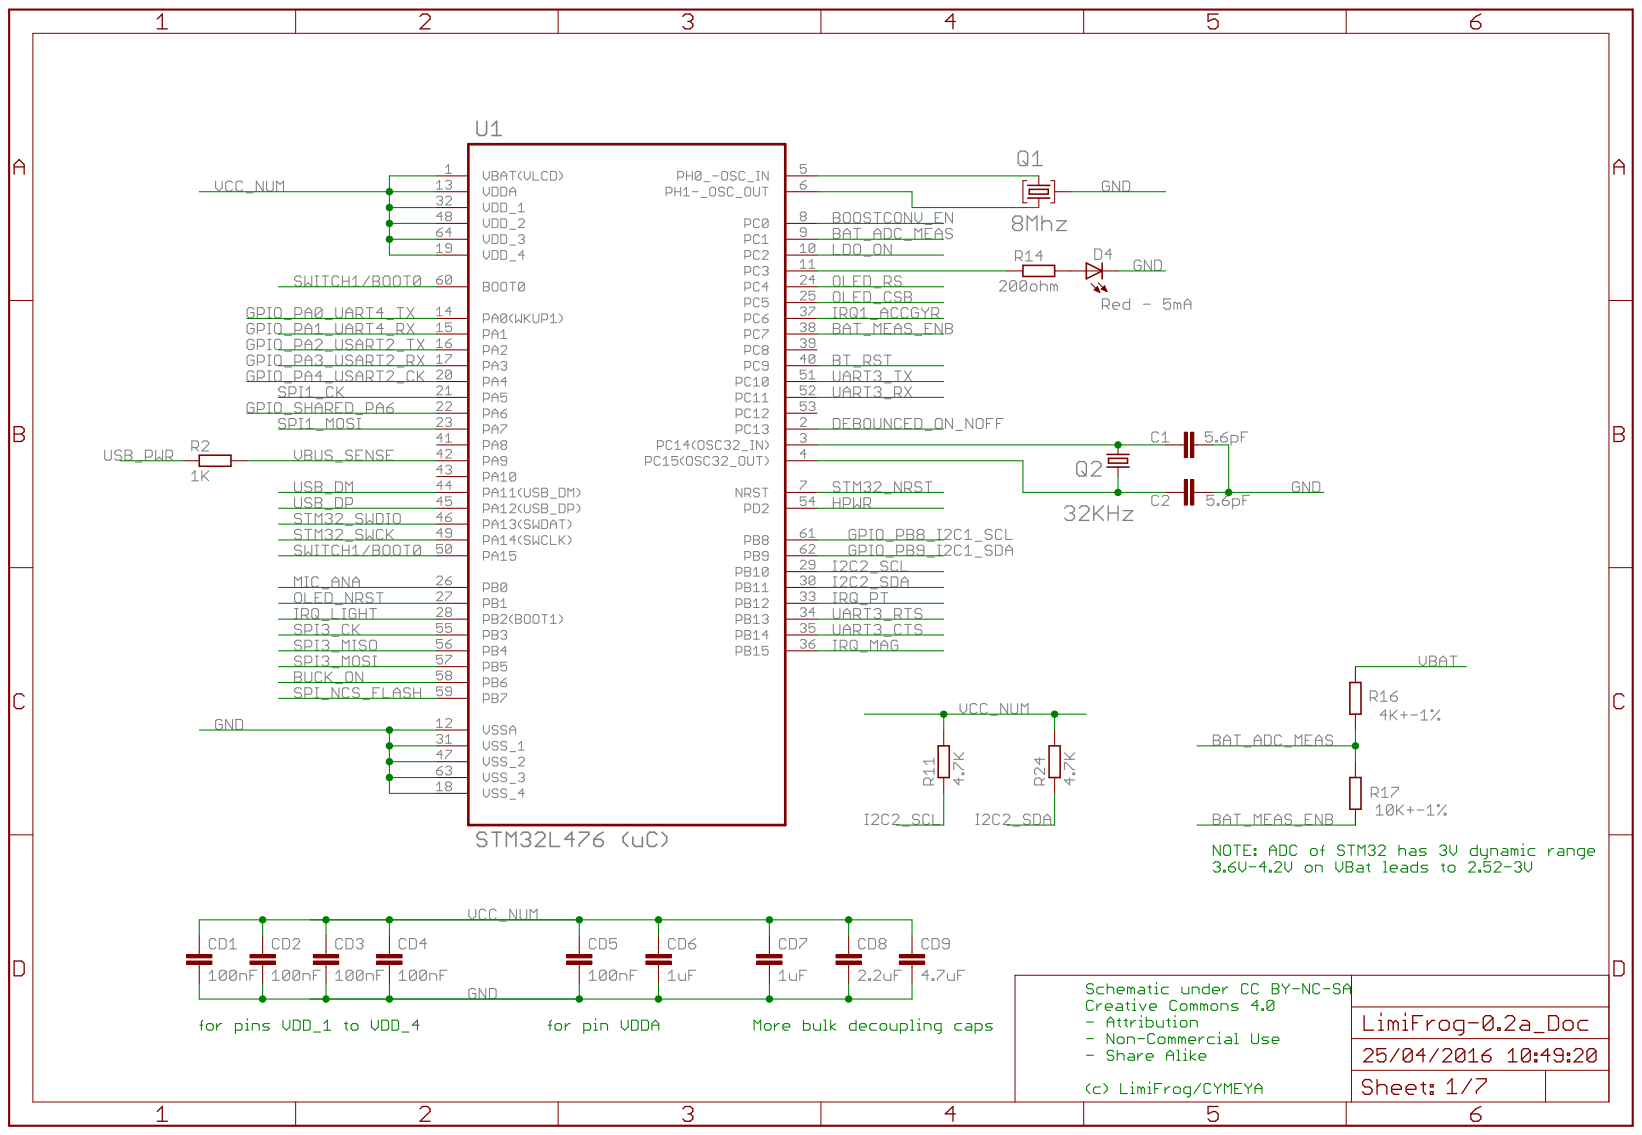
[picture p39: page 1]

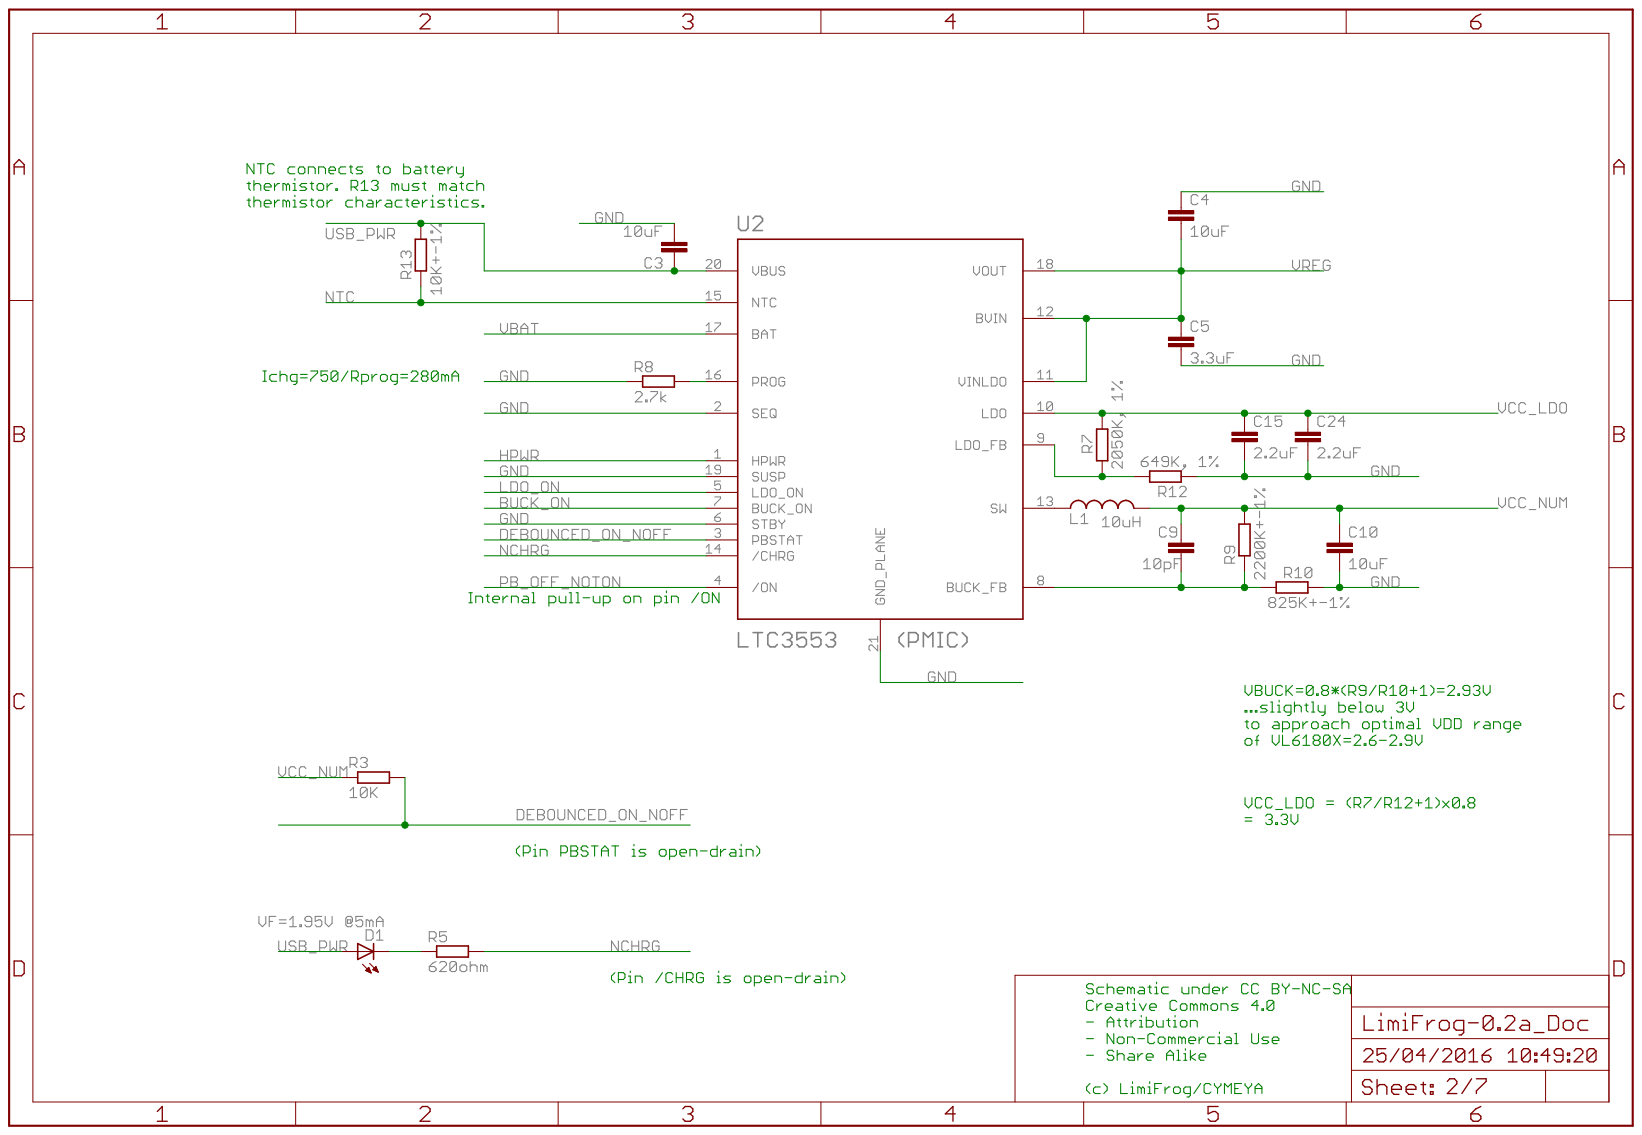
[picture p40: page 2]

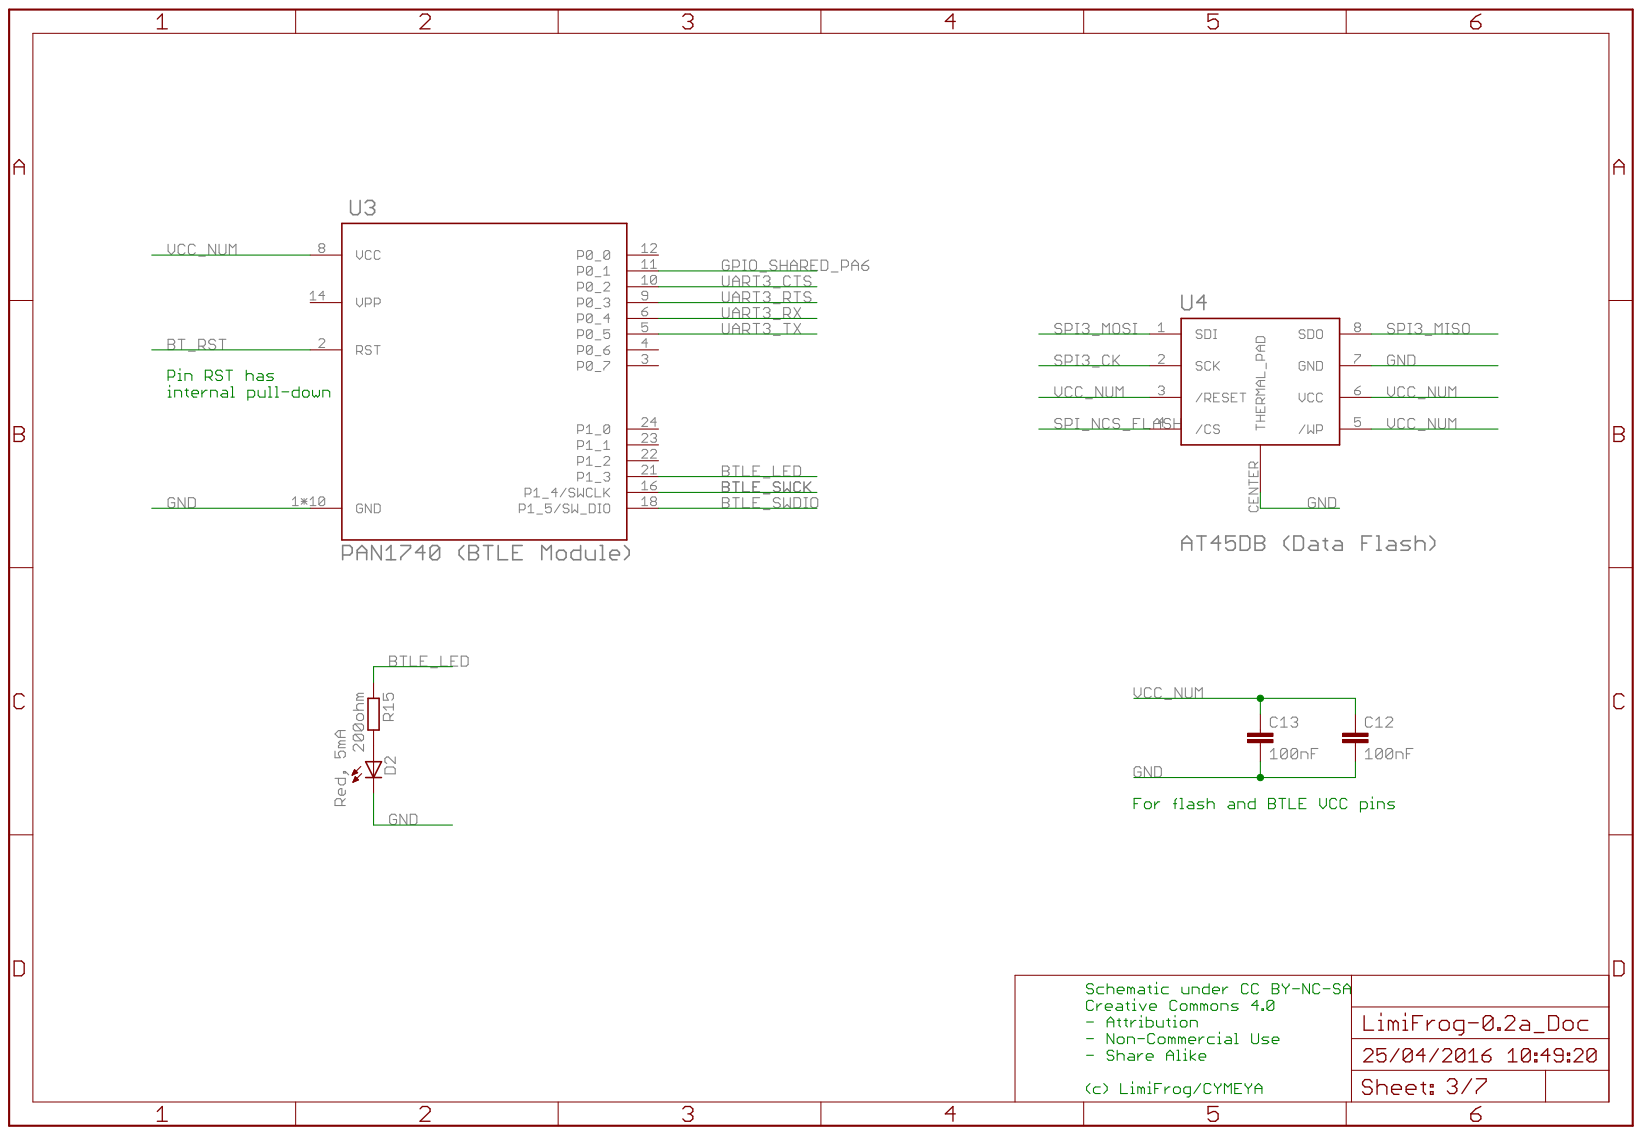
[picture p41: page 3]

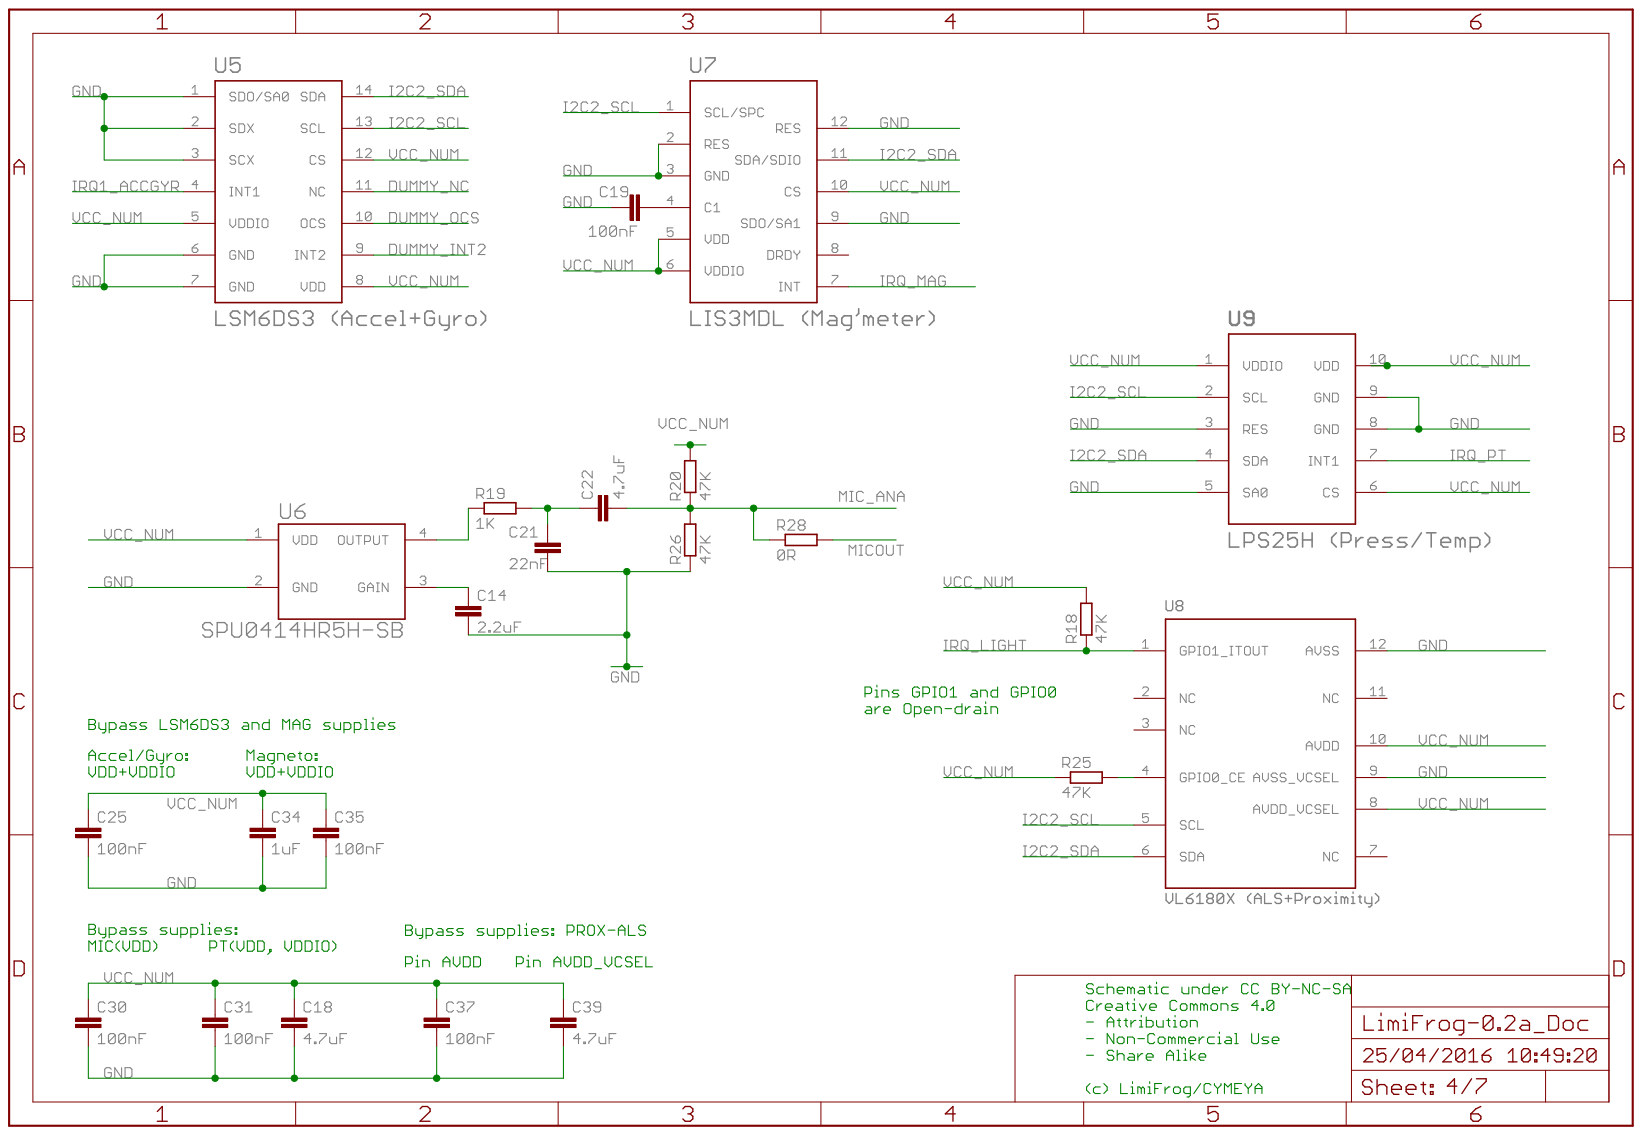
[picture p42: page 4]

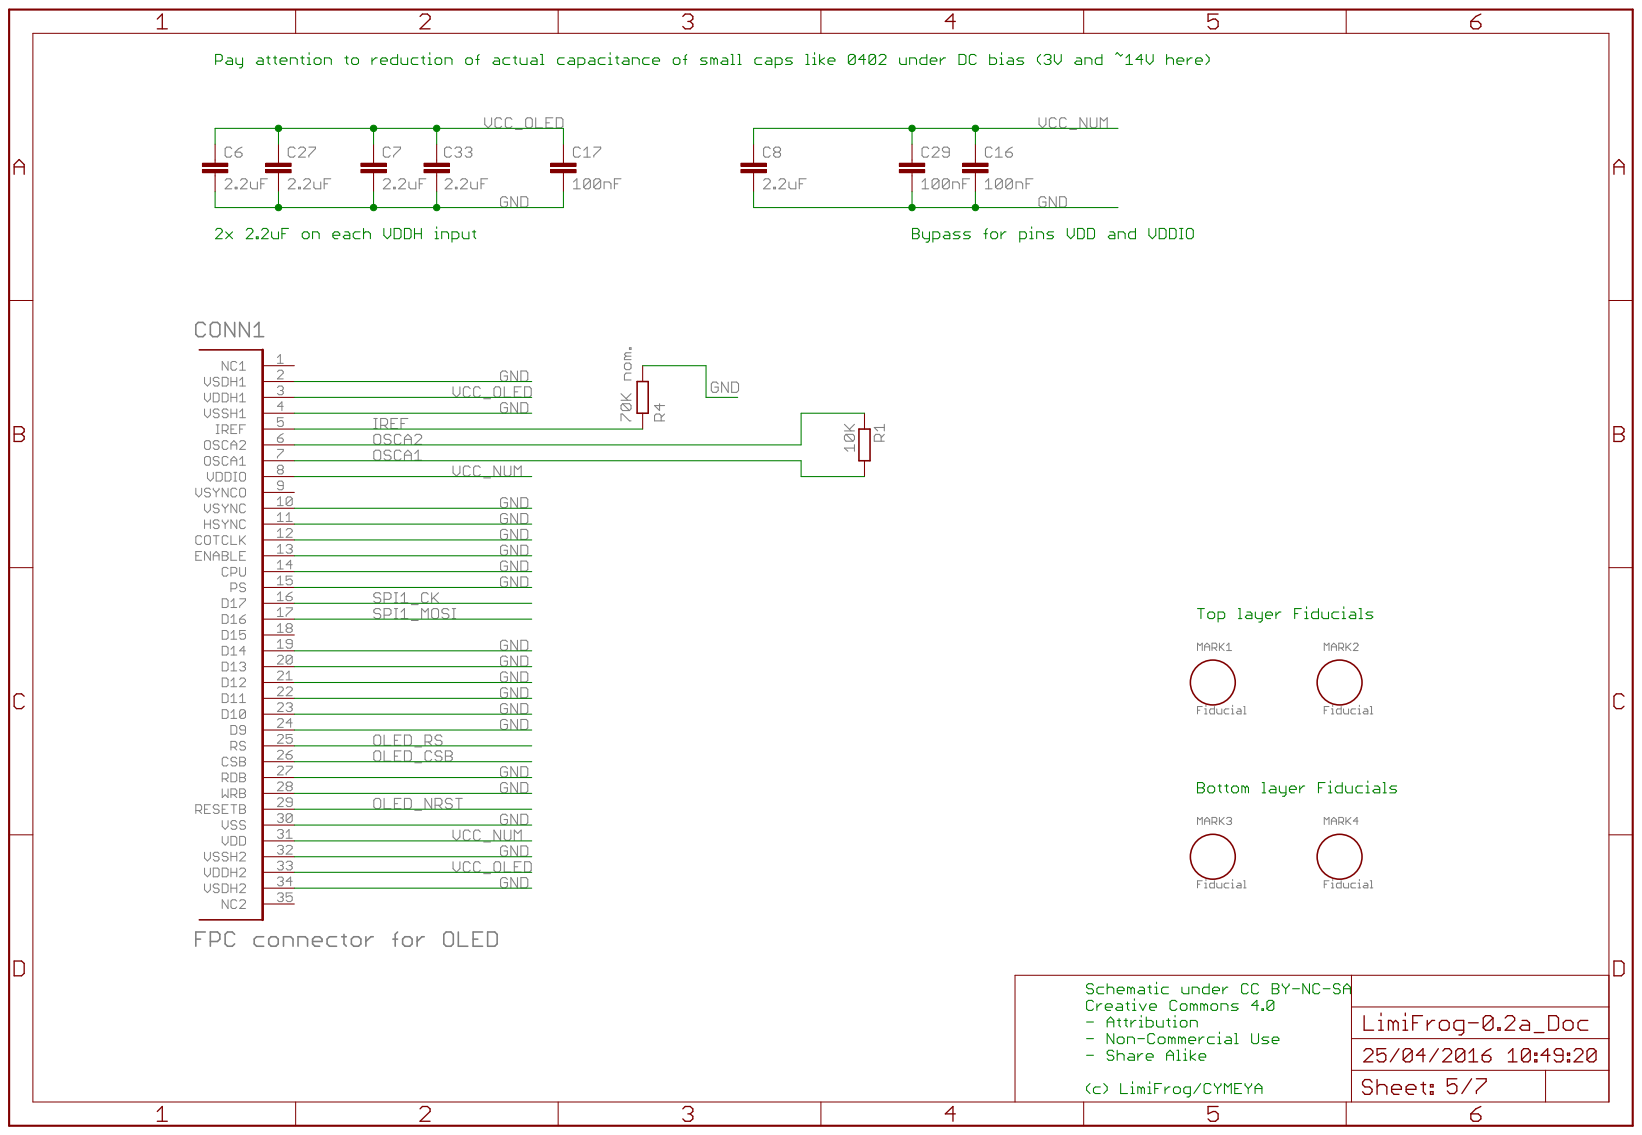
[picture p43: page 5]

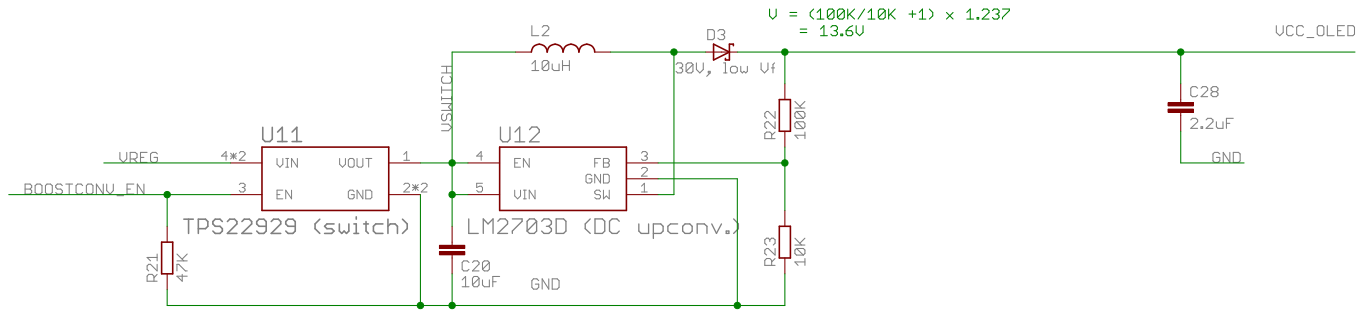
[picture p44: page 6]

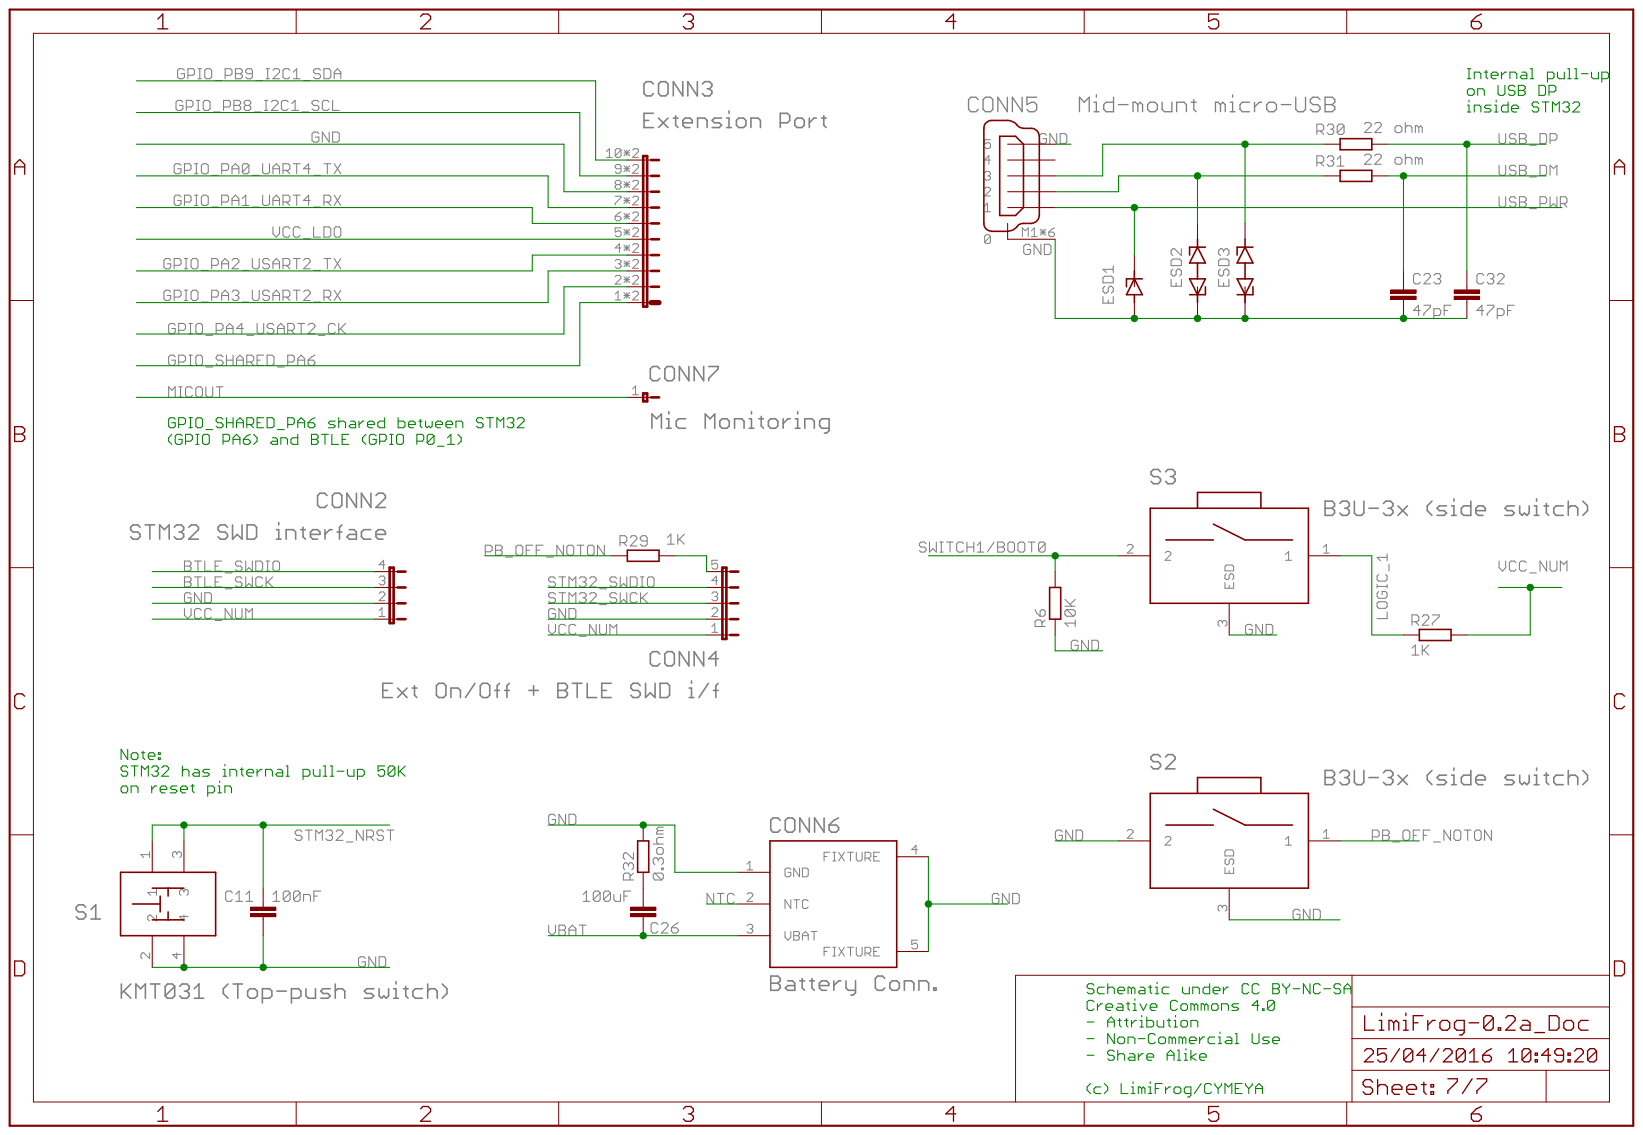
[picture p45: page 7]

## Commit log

2016-03-01 Initial Commit of Case Models
    [Case_Models.ods, LimiFrog-0.2-Case-Model.scad, Model_A-1.5.stl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]
2016-03-30 Add board information
2016-04-25 Schematic and licensing info
